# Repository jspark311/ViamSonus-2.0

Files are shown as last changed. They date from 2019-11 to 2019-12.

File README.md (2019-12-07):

# Viam Sonus 2.0

An audio router board with integrated volume control and buffered output.

### FEATURES:
  * 12 input channels that are arbitrarily routable to any of 8 output channels.
* Onboard digital potentiometers on the input side with non-volatile storage. Pots are logarithmic with zero-cross detection, and are paired in order with their input numbers on the board's silkscreen.
* Onboard op-amps on the output side with 300mA drive capability to provide buffering for direct-drive of line-level signals.
* Onboard buffered voltage divider with exposed output and 300mA drive capability to aid design and implementation of input buffers.
* Resistors added to the input-side of the switch, but after the potentiometers to allow for simple resistance mixing of signals simply by routing two inputs to a given output without risking damage. Some caveats apply (discussed below).
* Input-side is left free-form to allow use with single-ended (unbalanced) or differential (balanced) signals, and/or DC-biased sources.
* Safe for 5v audio signals.
* Isolated analog and digital power planes.
* Silkscreen reflects the envisioned usage (stereo signals), but the driver allows for easy grouping of any number of channels.
* Breadboard-friendly

#### [Hackaday.io Page](https://hackaday.io/project/168501-viam-sonus-20)

#### [Order from Tindie](https://www.tindie.com/products/18586/)

------------------------

### What is in this repository:

**./doc**:  Location for documentation

**./KiCAD**:  Hardware design files

**./Arduino**:  Arduino driver

**./linux**:  Linux wrappers and utility program

------------------------

### Encountering real world audio signals

#### Mixing, ducking, and cross-fade

To avoid damaging the board, input-side circuits should be designed to limit
peak channel currents if mixing is going to be used. Discourse on that topic can
be found in [a separate document](https://joshianlindsay.com/index.php?id=184).

#### Tips on channel layout

The driver sees the board as 12 mono inputs with discrete volume control routed
to 8 mono outputs. The driver presents a channel-grouping layer to the user application
that largely abstracts the underlying mono channels. But since the DS1881 was
intended as a stereo device, it has properties that support that use...

  * Resistances are matched on its two halves.
  * Both halves can be set with a single bus operation (and thus happen concurrently)

So if you intend on using Viam Sonus to handle stereo inputs, you _can_ use whatever
two channels for left and right that you like, and the driver will make it work. But it
will cost an extra bus operation to set the volume for the pair, and the channel
resistance match might be as loose as +/-20%. So if you can, you will get better
results by keeping stereo pairs on matched channels.

The output channels are also paired into the output buffers, but the choice of
keeping those matched (or not) will have less-tangible consequences.

------------------------

### Notes on driver features:

#### Channel grouping

By default, there are no channel groups, and the API operates on the level of
discrete mono channels. But many application will want to manage _groups of channels_.

Channel groups come in two flavors: Input and Output. Each type has a unique API.

#### Preserve-on-destroy

When the driver instance for the switch is destroyed, the default behavior is to
put the hardware into a known state (reset). This opens all routes. Use-cases
that want the hardware state to outlive the driver's life cycle are possible by
setting preserveOnDestroy(true) ahead of `init()`, like so...

    // Class initializes with the existing state of the hardware.
    vs.preserveOnDestroy(true);
    vs.init(&Wire);

Since `init()` will also call `reset()` by default, preserveOnDestroy must be
enabled prior to `init()` to achieve the desired result (both sides of the driver life cycle).

#### Preserving and restoring hardware states

The driver provides a means of cloning prior states to and from a buffer.
Possible reasons for doing this might be...

  * Higher bus efficiency during `init()`.
  * Major code savings, since you can skip configuring the hardware and the class with discrete function calls.
  * Storage of complete board configurations that can be fully re-established with a minimum of overhead.

Saving the current state can be done like this (from the example sketch)...

    uint8_t buffer[VIAMSONUS_SERIALIZE_SIZE];
    unsigned int written = vs.serialize(buffer, VIAMSONUS_SERIALIZE_SIZE);
    if (VIAMSONUS_SERIALIZE_SIZE == written) {
      // Everything worked. Do what you will with the buffer.
    }

Restoring the state from a buffer can be done either upon construction...

    uint8_t buf[VIAMSONUS_SERIALIZE_SIZE] = {
      0x01, 0x00, 0x00, 0x00, 0x00, 0x01, 0x70, 0x0A, 0x00, 0x00, 0x00, 0x00,
      0x00, 0x00, 0x00, 0x00, 0x00, 0x00, 0x00, 0x00, 0x00, 0x00, 0x01, 0x28,
      0x00, 0x3F, 0x3F, 0x06, 0x01, 0x28, 0x00, 0x3F, 0x3F, 0x06, 0x01, 0x29,
      0x00, 0x3F, 0x3F, 0x06, 0x01, 0x29, 0x00, 0x3F, 0x3F, 0x06, 0x01, 0x2A,
      0x00, 0x3F, 0x3F, 0x06, 0x01, 0x2A, 0x00, 0x3F, 0x3F, 0x06 ...
    };
    ViamSonus vs(buf, VIAMSONUS_SERIALIZE_SIZE);

...or after a successful `init()`...

    // Literally anywhere in the sketch...
    vs.unserialize(buf, VIAMSONUS_SERIALIZE_SIZE);

If done by construction, the configuration will be written to the class immediately,
and to the hardware during `init()`.

Invocation of `unserialize()` will immediately result in I/O as the new
configuration is imparted, but the fields (if any) that are otherwise required for
construction will be ignored.

------------------------

### Usage under Arduino

In order to use this driver, you also need the Arduino drivers for the elements on the board. Clone the following repos into your user libraries (wherever you keep them):

[DS1881 Driver](https://github.com/jspark311/DS1881-Breakout/tree/master/Arduino)

[ADG2128 Driver](https://github.com/jspark311/ADG2128-Breakout/tree/master/Arduino)

[StringBuilder and DataStructures](https://github.com/jspark311/CppPotpourri)

After you've done that, you ought to be able to include the ViamSonus driver.

------------------------

### Usage under Linux

Fortunately, the Viam Sonus router board doesn't have any interrupt pins, which makes running it in userland fairly easy with existing kernel drivers for i2c and GPIO. The reset pin isn't _strictly_ required. It can be tied high.

Just like the Arduino driver, you will need additional libraries. If you've already done
the setup for exposing the GPIO pin and i2c character device in your kernel config, you
ought to be able to do these things...

    git clone https://github.com/jspark311/ViamSonus-2.0.git
    cd ViamSonus-2.0/linux
    ./downloadDeps.sh
    make DEFAULT_I2C_DEV=/dev/i2c-1 DEFAULT_RESET_PIN=/sys/class/gpio/gpio18
    sudo make install

------------------------

Front | Back
:-------:|:------:
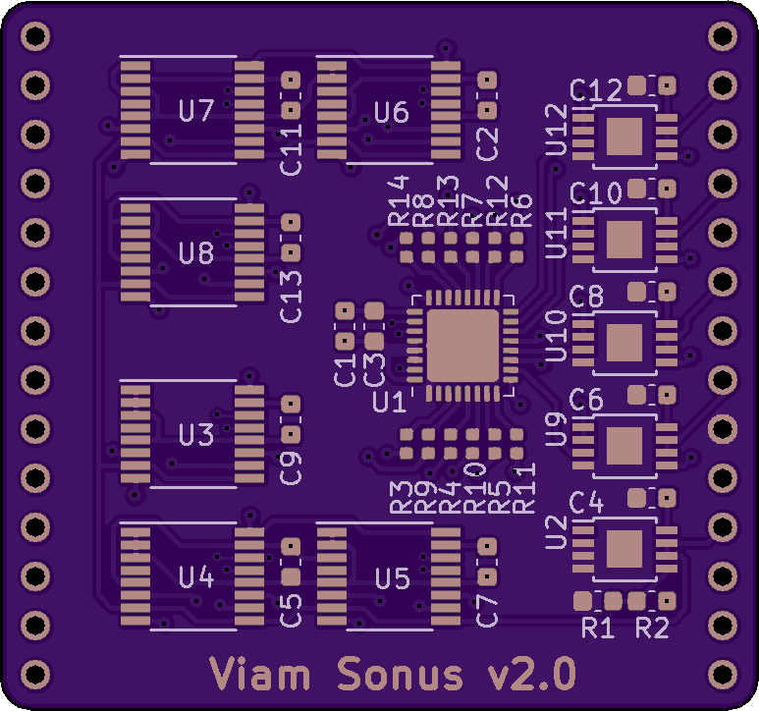
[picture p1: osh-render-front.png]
Front
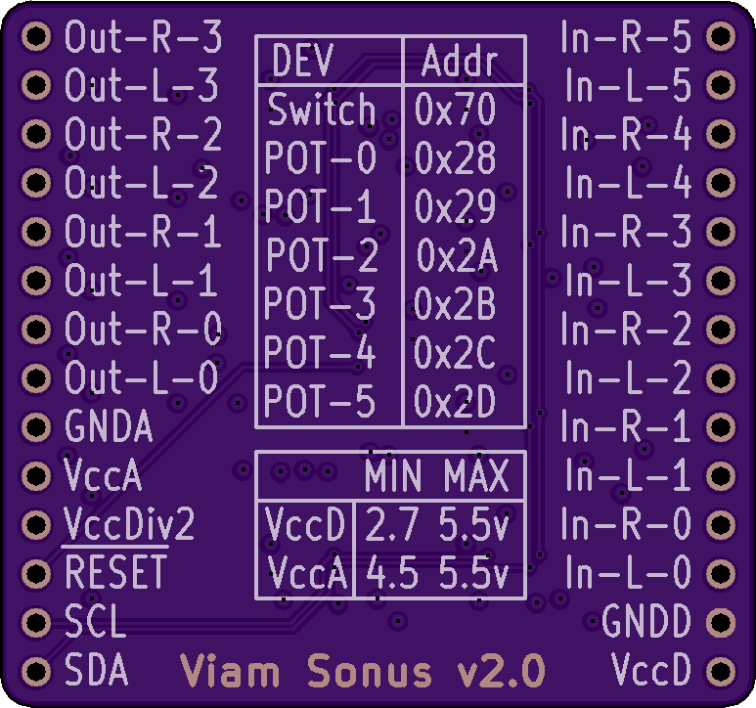
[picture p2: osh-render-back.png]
Back
  | 

[](https://oshpark.com/shared_projects/njoN7jnq)

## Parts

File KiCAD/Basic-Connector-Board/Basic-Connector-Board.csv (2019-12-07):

Reference | Value | Footprint | Datasheet | Digikey_Number | Manu_Name | Manu_Number
J11 | Conn_01x14_Male | Connector_PinHeader_2.54mm:PinHeader_1x14_P2.54mm_Vertical | ~
J12 | Conn_01x14_Male | Connector_PinHeader_2.54mm:PinHeader_1x14_P2.54mm_Vertical | ~
R6 | 20k | Resistor_SMD:R_0603_1608Metric | ~ | RNCP0603FTD20K0CT-ND | Stackpole Electronics Inc | RNCP0603FTD20K0
R5 | 20k | Resistor_SMD:R_0603_1608Metric | ~ | RNCP0603FTD20K0CT-ND | Stackpole Electronics Inc | RNCP0603FTD20K0
R12 | 20k | Resistor_SMD:R_0603_1608Metric | ~ | RNCP0603FTD20K0CT-ND | Stackpole Electronics Inc | RNCP0603FTD20K0
R11 | 20k | Resistor_SMD:R_0603_1608Metric | ~ | RNCP0603FTD20K0CT-ND | Stackpole Electronics Inc | RNCP0603FTD20K0
R4 | 20k | Resistor_SMD:R_0603_1608Metric | ~ | RNCP0603FTD20K0CT-ND | Stackpole Electronics Inc | RNCP0603FTD20K0
R3 | 20k | Resistor_SMD:R_0603_1608Metric | ~ | RNCP0603FTD20K0CT-ND | Stackpole Electronics Inc | RNCP0603FTD20K0
R10 | 20k | Resistor_SMD:R_0603_1608Metric | ~ | RNCP0603FTD20K0CT-ND | Stackpole Electronics Inc | RNCP0603FTD20K0
R9 | 20k | Resistor_SMD:R_0603_1608Metric | ~ | RNCP0603FTD20K0CT-ND | Stackpole Electronics Inc | RNCP0603FTD20K0
R2 | 20k | Resistor_SMD:R_0603_1608Metric | ~ | RNCP0603FTD20K0CT-ND | Stackpole Electronics Inc | RNCP0603FTD20K0
R1 | 20k | Resistor_SMD:R_0603_1608Metric | ~ | RNCP0603FTD20K0CT-ND | Stackpole Electronics Inc | RNCP0603FTD20K0
R8 | 20k | Resistor_SMD:R_0603_1608Metric | ~ | RNCP0603FTD20K0CT-ND | Stackpole Electronics Inc | RNCP0603FTD20K0
R7 | 20k | Resistor_SMD:R_0603_1608Metric | ~ | RNCP0603FTD20K0CT-ND | Stackpole Electronics Inc | RNCP0603FTD20K0
C20 | 3.3uF | Capacitor_SMD:CP_Elec_4x5.4 | ~ | 493-17493-1-ND | Nichicon | UUQ1H3R3MCL1GB
R18 | 20k | Resistor_SMD:R_0603_1608Metric | ~ | RNCP0603FTD20K0CT-ND | Stackpole Electronics Inc | RNCP0603FTD20K0
R17 | 20k | Resistor_SMD:R_0603_1608Metric | ~ | RNCP0603FTD20K0CT-ND | Stackpole Electronics Inc | RNCP0603FTD20K0
R24 | 20k | Resistor_SMD:R_0603_1608Metric | ~ | RNCP0603FTD20K0CT-ND | Stackpole Electronics Inc | RNCP0603FTD20K0
R23 | 20k | Resistor_SMD:R_0603_1608Metric | ~ | RNCP0603FTD20K0CT-ND | Stackpole Electronics Inc | RNCP0603FTD20K0
R16 | 20k | Resistor_SMD:R_0603_1608Metric | ~ | RNCP0603FTD20K0CT-ND | Stackpole Electronics Inc | RNCP0603FTD20K0
R15 | 20k | Resistor_SMD:R_0603_1608Metric | ~ | RNCP0603FTD20K0CT-ND | Stackpole Electronics Inc | RNCP0603FTD20K0
R22 | 20k | Resistor_SMD:R_0603_1608Metric | ~ | RNCP0603FTD20K0CT-ND | Stackpole Electronics Inc | RNCP0603FTD20K0
R21 | 20k | Resistor_SMD:R_0603_1608Metric | ~ | RNCP0603FTD20K0CT-ND | Stackpole Electronics Inc | RNCP0603FTD20K0
R14 | 20k | Resistor_SMD:R_0603_1608Metric | ~ | RNCP0603FTD20K0CT-ND | Stackpole Electronics Inc | RNCP0603FTD20K0
R13 | 20k | Resistor_SMD:R_0603_1608Metric | ~ | RNCP0603FTD20K0CT-ND | Stackpole Electronics Inc | RNCP0603FTD20K0
R20 | 20k | Resistor_SMD:R_0603_1608Metric | ~ | RNCP0603FTD20K0CT-ND | Stackpole Electronics Inc | RNCP0603FTD20K0
R19 | 20k | Resistor_SMD:R_0603_1608Metric | ~ | RNCP0603FTD20K0CT-ND | Stackpole Electronics Inc | RNCP0603FTD20K0
C3 | 100uF | Capacitor_SMD:CP_Elec_6.3x5.4_Nichicon | ~ | 493-16090-1-ND | Nichicon | UUQ0J101MCL1GB
J13 | Conn_01x04 | Connector_PinHeader_2.54mm:PinHeader_1x04_P2.54mm_Horizontal | ~
J14 | Conn_01x04 | Connector_PinHeader_2.54mm:PinHeader_1x04_P2.54mm_Horizontal | ~
C4 | 100uF | Capacitor_SMD:CP_Elec_6.3x5.4_Nichicon | ~ | 493-16090-1-ND | Nichicon | UUQ0J101MCL1GB
C2 | 100uF | Capacitor_SMD:CP_Elec_6.3x5.4_Nichicon | ~ | 493-16090-1-ND | Nichicon | UUQ0J101MCL1GB
C1 | 100uF | Capacitor_SMD:CP_Elec_6.3x5.4_Nichicon | ~ | 493-16090-1-ND | Nichicon | UUQ0J101MCL1GB
C11 | 100uF | Capacitor_SMD:CP_Elec_6.3x5.4_Nichicon | ~ | 493-16090-1-ND | Nichicon | UUQ0J101MCL1GB
C12 | 100uF | Capacitor_SMD:CP_Elec_6.3x5.4_Nichicon | ~ | 493-16090-1-ND | Nichicon | UUQ0J101MCL1GB
C13 | 100uF | Capacitor_SMD:CP_Elec_6.3x5.4_Nichicon | ~ | 493-16090-1-ND | Nichicon | UUQ0J101MCL1GB
C14 | 100uF | Capacitor_SMD:CP_Elec_6.3x5.4_Nichicon | ~ | 493-16090-1-ND | Nichicon | UUQ0J101MCL1GB
C19 | 3.3uF | Capacitor_SMD:CP_Elec_4x5.4 | ~ | 493-17493-1-ND | Nichicon | UUQ1H3R3MCL1GB
C18 | 3.3uF | Capacitor_SMD:CP_Elec_4x5.4 | ~ | 493-17493-1-ND | Nichicon | UUQ1H3R3MCL1GB
C17 | 3.3uF | Capacitor_SMD:CP_Elec_4x5.4 | ~ | 493-17493-1-ND | Nichicon | UUQ1H3R3MCL1GB
C16 | 3.3uF | Capacitor_SMD:CP_Elec_4x5.4 | ~ | 493-17493-1-ND | Nichicon | UUQ1H3R3MCL1GB
C15 | 3.3uF | Capacitor_SMD:CP_Elec_4x5.4 | ~ | 493-17493-1-ND | Nichicon | UUQ1H3R3MCL1GB
C10 | 3.3uF | Capacitor_SMD:CP_Elec_4x5.4 | ~ | 493-17493-1-ND | Nichicon | UUQ1H3R3MCL1GB
C9 | 3.3uF | Capacitor_SMD:CP_Elec_4x5.4 | ~ | 493-17493-1-ND | Nichicon | UUQ1H3R3MCL1GB
C8 | 3.3uF | Capacitor_SMD:CP_Elec_4x5.4 | ~ | 493-17493-1-ND | Nichicon | UUQ1H3R3MCL1GB
C7 | 3.3uF | Capacitor_SMD:CP_Elec_4x5.4 | ~ | 493-17493-1-ND | Nichicon | UUQ1H3R3MCL1GB
C6 | 3.3uF | Capacitor_SMD:CP_Elec_4x5.4 | ~ | 493-17493-1-ND | Nichicon | UUQ1H3R3MCL1GB
C5 | 3.3uF | Capacitor_SMD:CP_Elec_4x5.4 | ~ | 493-17493-1-ND | Nichicon | UUQ1H3R3MCL1GB
U1 | LM1085 | Package_TO_SOT_SMD:TO-263-3_TabPin2 |  | 296-35391-1-ND | Texas Instruments | LM1085ISX-5.0/NOPB
C21 | 10uF | Capacitor_SMD:CP_Elec_4x5.4 | ~ | 493-14558-1-ND | Nichicon | UUQ11C100MCL1GB
C22 | 10uF | Capacitor_SMD:CP_Elec_4x5.4 | ~ | 493-14558-1-ND | Nichicon | UUQ11C100MCL1GB
R38 | 2k | Resistor_SMD:R_0603_1608Metric | ~ | RNCP0603FTD2K00CT-ND | Stackpole Electronics Inc | RNCP0603FTD2K00
R37 | 2k | Resistor_SMD:R_0603_1608Metric | ~ | RNCP0603FTD2K00CT-ND | Stackpole Electronics Inc | RNCP0603FTD2K00
R36 | 2k | Resistor_SMD:R_0603_1608Metric | ~ | RNCP0603FTD2K00CT-ND | Stackpole Electronics Inc | RNCP0603FTD2K00
R35 | 2k | Resistor_SMD:R_0603_1608Metric | ~ | RNCP0603FTD2K00CT-ND | Stackpole Electronics Inc | RNCP0603FTD2K00
R34 | 2k | Resistor_SMD:R_0603_1608Metric | ~ | RNCP0603FTD2K00CT-ND | Stackpole Electronics Inc | RNCP0603FTD2K00
R33 | 2k | Resistor_SMD:R_0603_1608Metric | ~ | RNCP0603FTD2K00CT-ND | Stackpole Electronics Inc | RNCP0603FTD2K00
R28 | 2k | Resistor_SMD:R_0603_1608Metric | ~ | RNCP0603FTD2K00CT-ND | Stackpole Electronics Inc | RNCP0603FTD2K00
R27 | 2k | Resistor_SMD:R_0603_1608Metric | ~ | RNCP0603FTD2K00CT-ND | Stackpole Electronics Inc | RNCP0603FTD2K00
R30 | 2k | Resistor_SMD:R_0603_1608Metric | ~ | RNCP0603FTD2K00CT-ND | Stackpole Electronics Inc | RNCP0603FTD2K00
R29 | 2k | Resistor_SMD:R_0603_1608Metric | ~ | RNCP0603FTD2K00CT-ND | Stackpole Electronics Inc | RNCP0603FTD2K00
R32 | 2k | Resistor_SMD:R_0603_1608Metric | ~ | RNCP0603FTD2K00CT-ND | Stackpole Electronics Inc | RNCP0603FTD2K00
R31 | 2k | Resistor_SMD:R_0603_1608Metric | ~ | RNCP0603FTD2K00CT-ND | Stackpole Electronics Inc | RNCP0603FTD2K00
R25 | 2k | Resistor_SMD:R_0603_1608Metric | ~ | RNCP0603FTD2K00CT-ND | Stackpole Electronics Inc | RNCP0603FTD2K00
R26 | 2k | Resistor_SMD:R_0603_1608Metric | ~ | RNCP0603FTD2K00CT-ND | Stackpole Electronics Inc | RNCP0603FTD2K00
C23 | 100uF | Capacitor_SMD:CP_Elec_6.3x5.4_Nichicon | ~ | 493-16090-1-ND | Nichicon | UUQ0J101MCL1GB
C24 | 100uF | Capacitor_SMD:CP_Elec_6.3x5.4_Nichicon | ~ | 493-16090-1-ND | Nichicon | UUQ0J101MCL1GB
J4 | AudioJack3_Ground_Switch | Footprints:SJ2-3593D-SMT-TR | ~ | CP-SJ2-3593D-SMT-CT-ND | CUI Devices | SJ2-3593D-SMT-TR
J5 | AudioJack3_Ground_Switch | Footprints:SJ2-3593D-SMT-TR | ~ | CP-SJ2-3593D-SMT-CT-ND | CUI Devices | SJ2-3593D-SMT-TR
J6 | AudioJack3_Ground_Switch | Footprints:SJ2-3593D-SMT-TR | ~ | CP-SJ2-3593D-SMT-CT-ND | CUI Devices | SJ2-3593D-SMT-TR
J3 | AudioJack3_Ground_Switch | Footprints:SJ2-3593D-SMT-TR | ~ | CP-SJ2-3593D-SMT-CT-ND | CUI Devices | SJ2-3593D-SMT-TR
J2 | AudioJack3_Ground_Switch | Footprints:SJ2-3593D-SMT-TR | ~ | CP-SJ2-3593D-SMT-CT-ND | CUI Devices | SJ2-3593D-SMT-TR
J1 | AudioJack3_Ground_Switch | Footprints:SJ2-3593D-SMT-TR | ~ | CP-SJ2-3593D-SMT-CT-ND | CUI Devices | SJ2-3593D-SMT-TR
J7 | AudioJack3_Ground_Switch | Footprints:SJ2-3593D-SMT-TR | ~ | CP-SJ2-3593D-SMT-CT-ND | CUI Devices | SJ2-3593D-SMT-TR
J8 | AudioJack3_Ground_Switch | Footprints:SJ2-3593D-SMT-TR | ~ | CP-SJ2-3593D-SMT-CT-ND | CUI Devices | SJ2-3593D-SMT-TR
J10 | AudioJack3_Ground_Switch | Footprints:SJ2-3593D-SMT-TR | ~ | CP-SJ2-3593D-SMT-CT-ND | CUI Devices | SJ2-3593D-SMT-TR
J9 | AudioJack3_Ground_Switch | Footprints:SJ2-3593D-SMT-TR | ~ | CP-SJ2-3593D-SMT-CT-ND | CUI Devices | SJ2-3593D-SMT-TR
R42 | 20k | Resistor_SMD:R_0603_1608Metric | ~ | RNCP0603FTD20K0CT-ND | Stackpole Electronics Inc | RNCP0603FTD20K0
R44 | 20k | Resistor_SMD:R_0603_1608Metric | ~ | RNCP0603FTD20K0CT-ND | Stackpole Electronics Inc | RNCP0603FTD20K0
R39 | 20k | Resistor_SMD:R_0603_1608Metric | ~ | RNCP0603FTD20K0CT-ND | Stackpole Electronics Inc | RNCP0603FTD20K0
R43 | 20k | Resistor_SMD:R_0603_1608Metric | ~ | RNCP0603FTD20K0CT-ND | Stackpole Electronics Inc | RNCP0603FTD20K0
R40 | 20k | Resistor_SMD:R_0603_1608Metric | ~ | RNCP0603FTD20K0CT-ND | Stackpole Electronics Inc | RNCP0603FTD20K0
R41 | 20k | Resistor_SMD:R_0603_1608Metric | ~ | RNCP0603FTD20K0CT-ND | Stackpole Electronics Inc | RNCP0603FTD20K0
J15 | 6.5 - 20v | Footprints:PJ-063AH | ~ | CP-063AH-ND | CUI Devices | PJ-063AH

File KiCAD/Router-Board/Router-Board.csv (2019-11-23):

Reference | Value | Footprint | Datasheet | Digikey_Num | Manu_Name | Manu_Num
U1 | ADG2128 | Package_DFN_QFN:QFN-32-1EP_5x5mm_P0.5mm_EP3.65x3.65mm |  | ADG2128YCPZ-REEL7CT-ND | Analog Devices Inc. | ADG2128YCPZ-REEL7
U3 | DS1881E-050+ | Package_SO:TSSOP-16_4.4x5mm_P0.65mm |  | DS1881E-050+-ND | Maxim Integrated | DS1881E-050+
U11 | LME49726MY/NOPB | Footprints:TSSOP-8_3x3mm_P0.65mm-EP |  | LME49726MY/NOPBCT-ND | Texas Instruments | LME49726MY/NOPB
C10 | 1uF | Capacitor_SMD:C_0603_1608Metric | ~ | 445-13228-1-ND | TDK Corporation | CGB3B1X7R1A105K055AC
U4 | DS1881E-050+ | Package_SO:TSSOP-16_4.4x5mm_P0.65mm |  | DS1881E-050+-ND | Maxim Integrated | DS1881E-050+
U5 | DS1881E-050+ | Package_SO:TSSOP-16_4.4x5mm_P0.65mm |  | DS1881E-050+-ND | Maxim Integrated | DS1881E-050+
U6 | DS1881E-050+ | Package_SO:TSSOP-16_4.4x5mm_P0.65mm |  | DS1881E-050+-ND | Maxim Integrated | DS1881E-050+
U7 | DS1881E-050+ | Package_SO:TSSOP-16_4.4x5mm_P0.65mm |  | DS1881E-050+-ND | Maxim Integrated | DS1881E-050+
U8 | DS1881E-050+ | Package_SO:TSSOP-16_4.4x5mm_P0.65mm |  | DS1881E-050+-ND | Maxim Integrated | DS1881E-050+
U10 | LME49726MY/NOPB | Footprints:TSSOP-8_3x3mm_P0.65mm-EP |  | LME49726MY/NOPBCT-ND | Texas Instruments | LME49726MY/NOPB
U9 | LME49726MY/NOPB | Footprints:TSSOP-8_3x3mm_P0.65mm-EP |  | LME49726MY/NOPBCT-ND | Texas Instruments | LME49726MY/NOPB
U12 | LME49726MY/NOPB | Footprints:TSSOP-8_3x3mm_P0.65mm-EP |  | LME49726MY/NOPBCT-ND | Texas Instruments | LME49726MY/NOPB
U2 | LME49726MY/NOPB | Footprints:TSSOP-8_3x3mm_P0.65mm-EP |  | LME49726MY/NOPBCT-ND | Texas Instruments | LME49726MY/NOPB
R1 | 51k | Resistor_SMD:R_0603_1608Metric | ~ | RMCF0603FT51K0CT-ND | Stackpole Electronics Inc | Stackpole Electronics Inc
R3 | 330 | Resistor_SMD:R_0402_1005Metric | ~ | 2019-RK73H1ETTP3300FCT-ND | KOA Speer Electronics, Inc. | RK73H1ETTP3300F
J2 | Conn_01x14_Male | Connector_PinHeader_2.54mm:PinHeader_1x14_P2.54mm_Vertical | ~
J3 | Conn_01x14_Male | Connector_PinHeader_2.54mm:PinHeader_1x14_P2.54mm_Vertical | ~
C8 | 1uF | Capacitor_SMD:C_0603_1608Metric | ~ | 445-13228-1-ND | TDK Corporation | CGB3B1X7R1A105K055AC
C6 | 1uF | Capacitor_SMD:C_0603_1608Metric | ~ | 445-13228-1-ND | TDK Corporation | CGB3B1X7R1A105K055AC
C4 | 1uF | Capacitor_SMD:C_0603_1608Metric | ~ | 445-13228-1-ND | TDK Corporation | CGB3B1X7R1A105K055AC
C12 | 1uF | Capacitor_SMD:C_0603_1608Metric | ~ | 445-13228-1-ND | TDK Corporation | CGB3B1X7R1A105K055AC
C1 | 1uF | Capacitor_SMD:C_0603_1608Metric | ~ | 445-13228-1-ND | TDK Corporation | CGB3B1X7R1A105K055AC
C2 | 1uF | Capacitor_SMD:C_0603_1608Metric | ~ | 445-13228-1-ND | TDK Corporation | CGB3B1X7R1A105K055AC
C3 | 1uF | Capacitor_SMD:C_0603_1608Metric | ~ | 445-13228-1-ND | TDK Corporation | CGB3B1X7R1A105K055AC
C5 | 1uF | Capacitor_SMD:C_0603_1608Metric | ~ | 445-13228-1-ND | TDK Corporation | CGB3B1X7R1A105K055AC
C7 | 1uF | Capacitor_SMD:C_0603_1608Metric | ~ | 445-13228-1-ND | TDK Corporation | CGB3B1X7R1A105K055AC
C9 | 1uF | Capacitor_SMD:C_0603_1608Metric | ~ | 445-13228-1-ND | TDK Corporation | CGB3B1X7R1A105K055AC
C11 | 1uF | Capacitor_SMD:C_0603_1608Metric | ~ | 445-13228-1-ND | TDK Corporation | CGB3B1X7R1A105K055AC
C13 | 1uF | Capacitor_SMD:C_0603_1608Metric | ~ | 445-13228-1-ND | TDK Corporation | CGB3B1X7R1A105K055AC
R2 | 51k | Resistor_SMD:R_0603_1608Metric | ~ | RMCF0603FT51K0CT-ND | Stackpole Electronics Inc | Stackpole Electronics Inc
R9 | 330 | Resistor_SMD:R_0402_1005Metric | ~ | 2019-RK73H1ETTP3300FCT-ND | KOA Speer Electronics, Inc. | RK73H1ETTP3300F
R10 | 330 | Resistor_SMD:R_0402_1005Metric | ~ | 2019-RK73H1ETTP3300FCT-ND | KOA Speer Electronics, Inc. | RK73H1ETTP3300F
R11 | 330 | Resistor_SMD:R_0402_1005Metric | ~ | 2019-RK73H1ETTP3300FCT-ND | KOA Speer Electronics, Inc. | RK73H1ETTP3300F
R12 | 330 | Resistor_SMD:R_0402_1005Metric | ~ | 2019-RK73H1ETTP3300FCT-ND | KOA Speer Electronics, Inc. | RK73H1ETTP3300F
R13 | 330 | Resistor_SMD:R_0402_1005Metric | ~ | 2019-RK73H1ETTP3300FCT-ND | KOA Speer Electronics, Inc. | RK73H1ETTP3300F
R14 | 330 | Resistor_SMD:R_0402_1005Metric | ~ | 2019-RK73H1ETTP3300FCT-ND | KOA Speer Electronics, Inc. | RK73H1ETTP3300F
R8 | 330 | Resistor_SMD:R_0402_1005Metric | ~ | 2019-RK73H1ETTP3300FCT-ND | KOA Speer Electronics, Inc. | RK73H1ETTP3300F
R7 | 330 | Resistor_SMD:R_0402_1005Metric | ~ | 2019-RK73H1ETTP3300FCT-ND | KOA Speer Electronics, Inc. | RK73H1ETTP3300F
R6 | 330 | Resistor_SMD:R_0402_1005Metric | ~ | 2019-RK73H1ETTP3300FCT-ND | KOA Speer Electronics, Inc. | RK73H1ETTP3300F
R5 | 330 | Resistor_SMD:R_0402_1005Metric | ~ | 2019-RK73H1ETTP3300FCT-ND | KOA Speer Electronics, Inc. | RK73H1ETTP3300F
R4 | 330 | Resistor_SMD:R_0402_1005Metric | ~ | 2019-RK73H1ETTP3300FCT-ND | KOA Speer Electronics, Inc. | RK73H1ETTP3300F

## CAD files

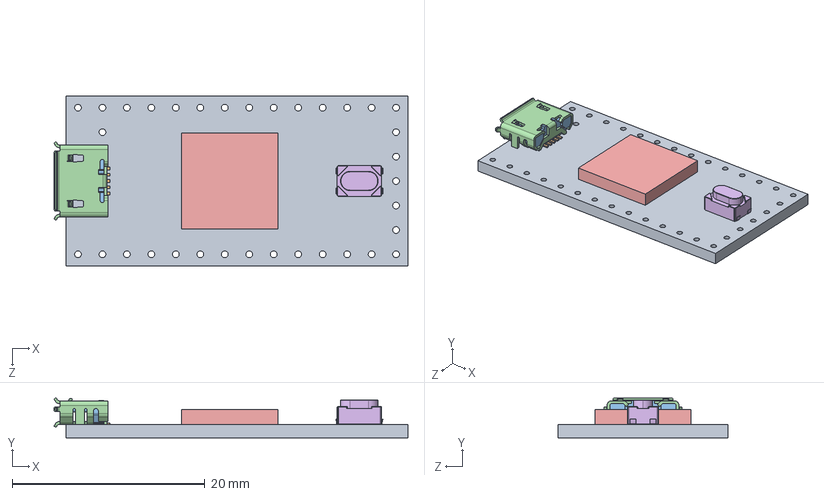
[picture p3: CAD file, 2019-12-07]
KiCAD/Footprints/Teensy_4.0_Assembly.STEP
36.8 x 4.12 x 17.7 mm
Teensy_4.0_PCB
Micro USB-B Female 5Pin SMD
NXP iMXRT1062
SKRPACE010 v4

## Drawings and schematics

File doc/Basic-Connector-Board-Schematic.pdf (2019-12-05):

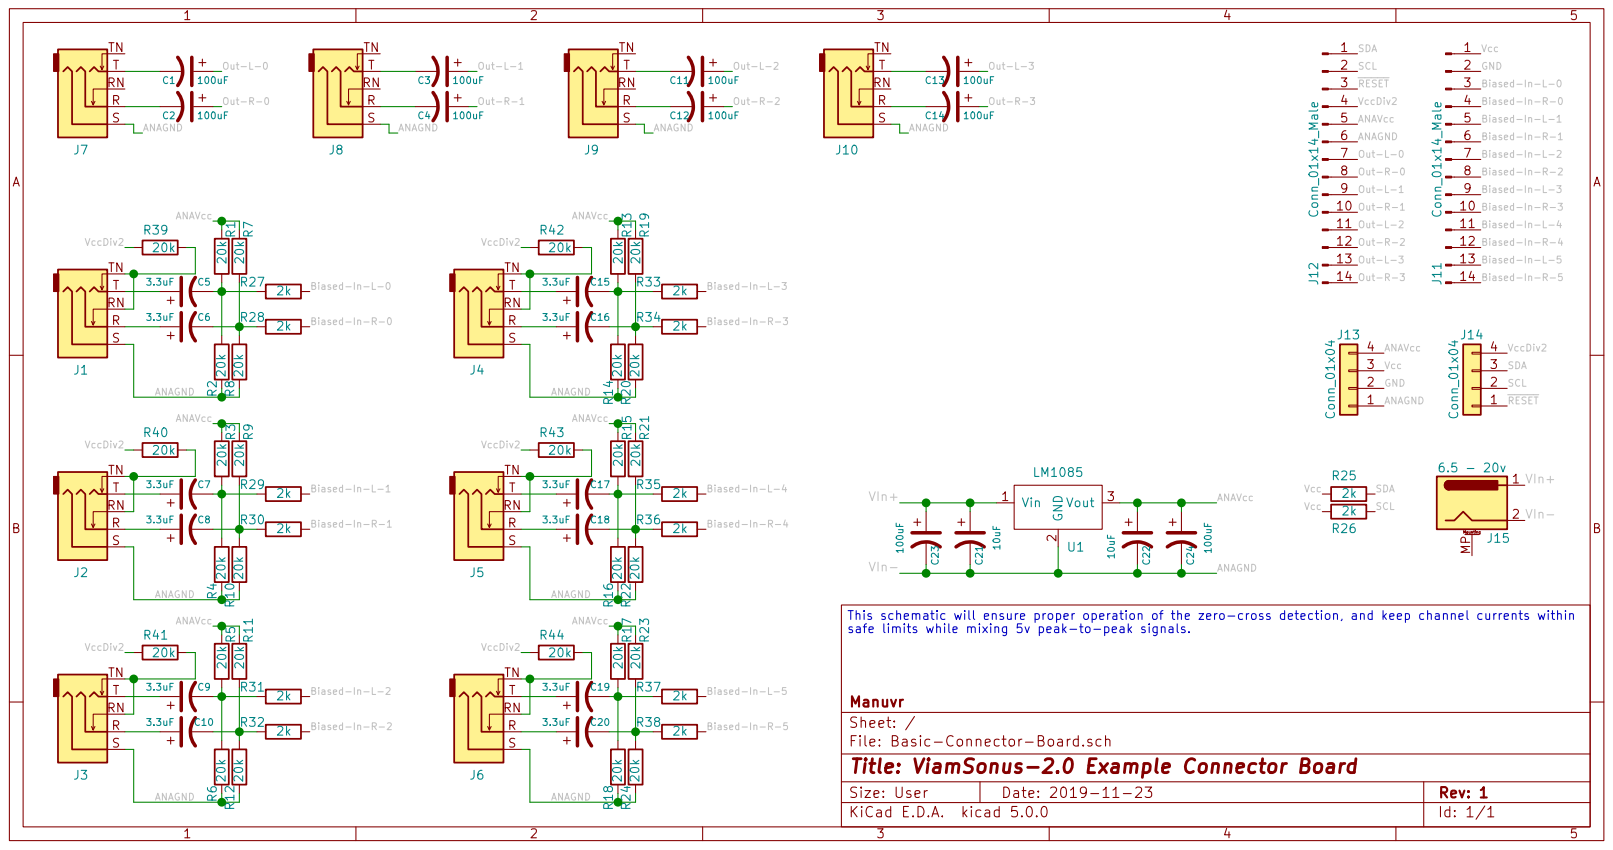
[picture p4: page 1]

Biased-In-L-0 Biased-In-L-1 Biased-In-L-2 Biased-In-L-3 Biased-In-L-4 Biased-In-L-5 Biased-In-R-0 Biased-In-R-1 Biased-In-R-2 Biased-In-R-3 Biased-In-R-4 Biased-In-R-5 Out-L-0 Out-L-1 Out-L-2 Out-L-3 Out-R-0 Out-R-1 Out-R-2 Out-R-3 R6 20k ANAGND

This schematic will ensure proper operation of the zero-cross detection, and keep channel currents within

File: Basic-Connector-Board.sch Sheet: / Manuvr

Id: 1/1 Title: ViamSonus-2.0 Example Connector Board

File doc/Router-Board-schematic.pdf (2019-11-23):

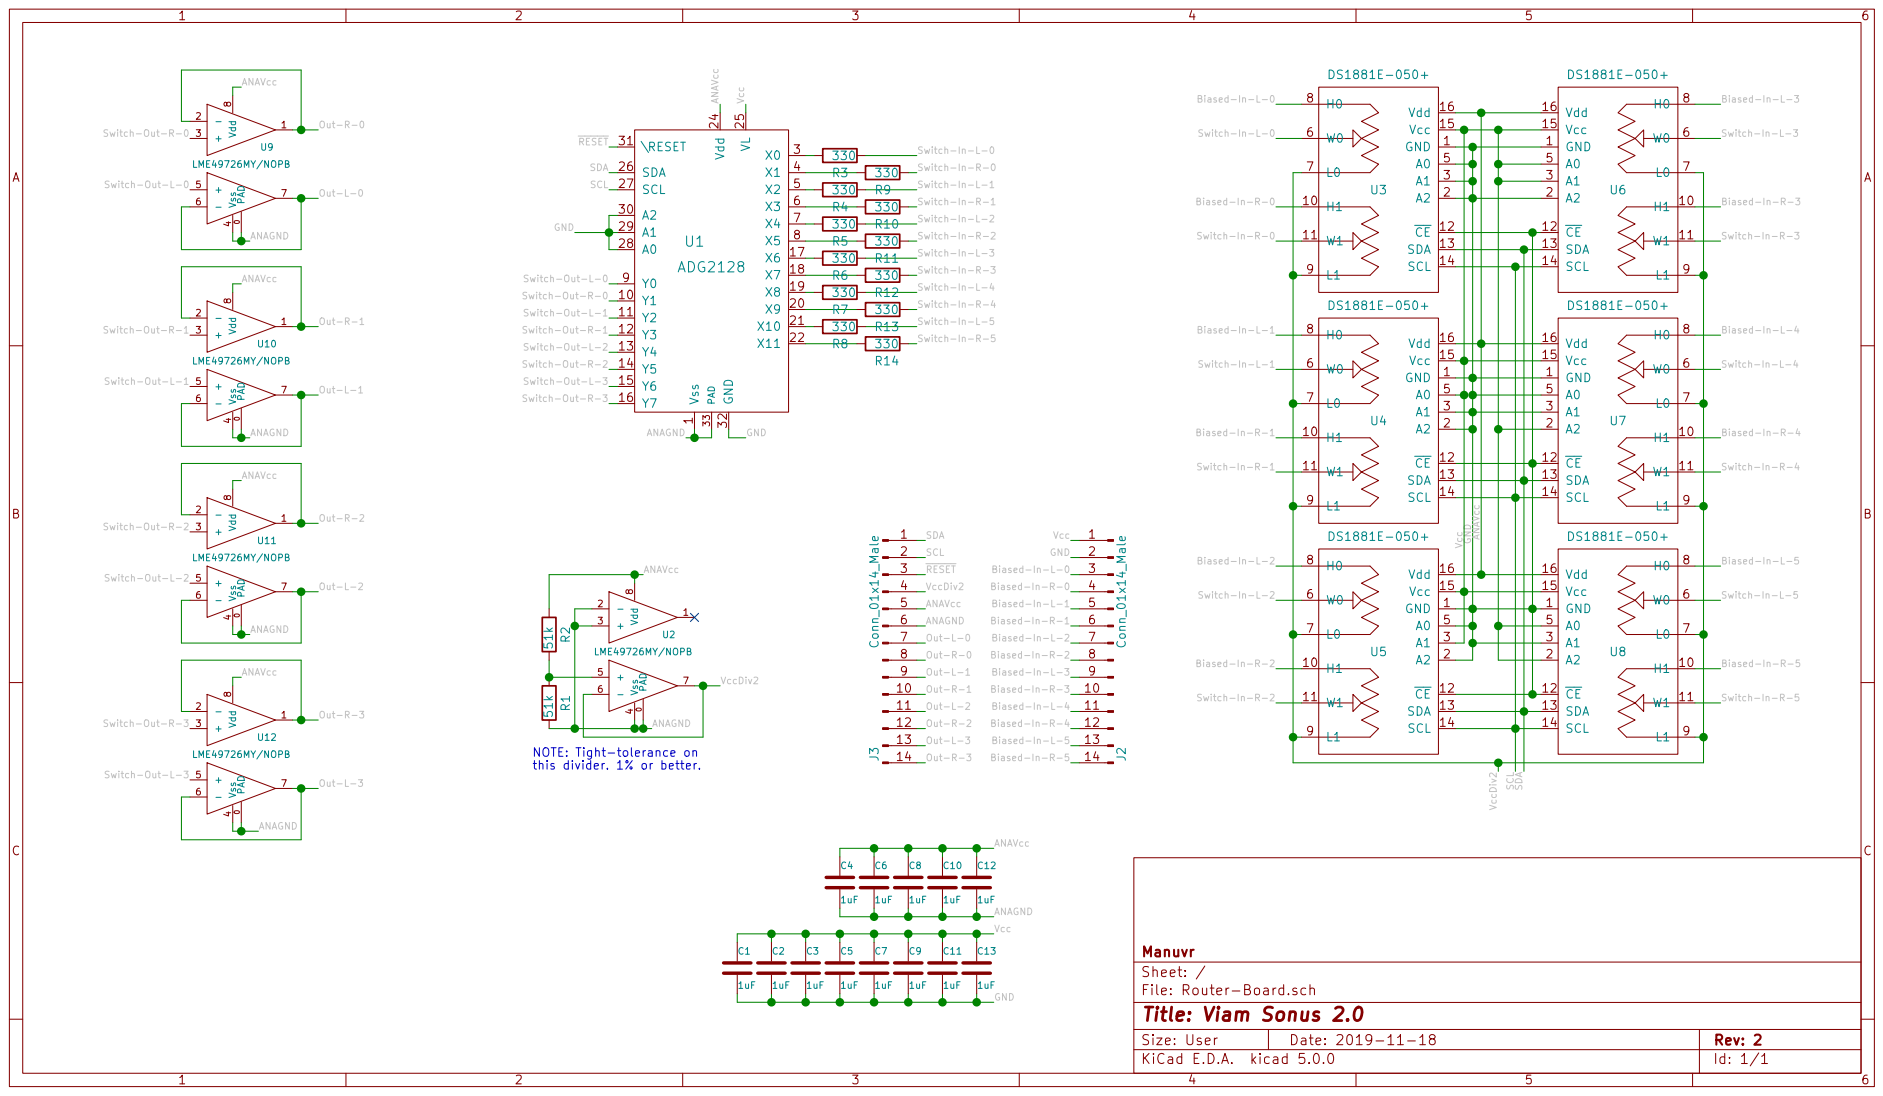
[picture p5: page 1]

Switch-Out-R-0 Switch-Out-R-1 Switch-Out-R-2 Switch-Out-R-3
Switch-Out-L-0 Switch-Out-L-1 Switch-Out-L-2 Switch-Out-L-3

Out-R-0 Out-R-1 Out-R-2 Out-R-3

Biased-In-L-0 Biased-In-L-1 Biased-In-L-2
Switch-In-L-0 Switch-In-L-1 Switch-In-L-2
Biased-In-R-0 Biased-In-R-1 Biased-In-R-2

Biased-In-R-3 Biased-In-R-4 Biased-In-R-5

Switch-In-L-3 Switch-In-L-4 Switch-In-L-5 Switch-In-R-0 Switch-In-R-1 Switch-In-R-2

Out-L-0 Out-L-1 Out-L-2 Out-L-3

Switch-In-R-3 Switch-In-R-4 Switch-In-R-5 SCL SDA

Id: 1/1 Title: Viam Sonus 2.0

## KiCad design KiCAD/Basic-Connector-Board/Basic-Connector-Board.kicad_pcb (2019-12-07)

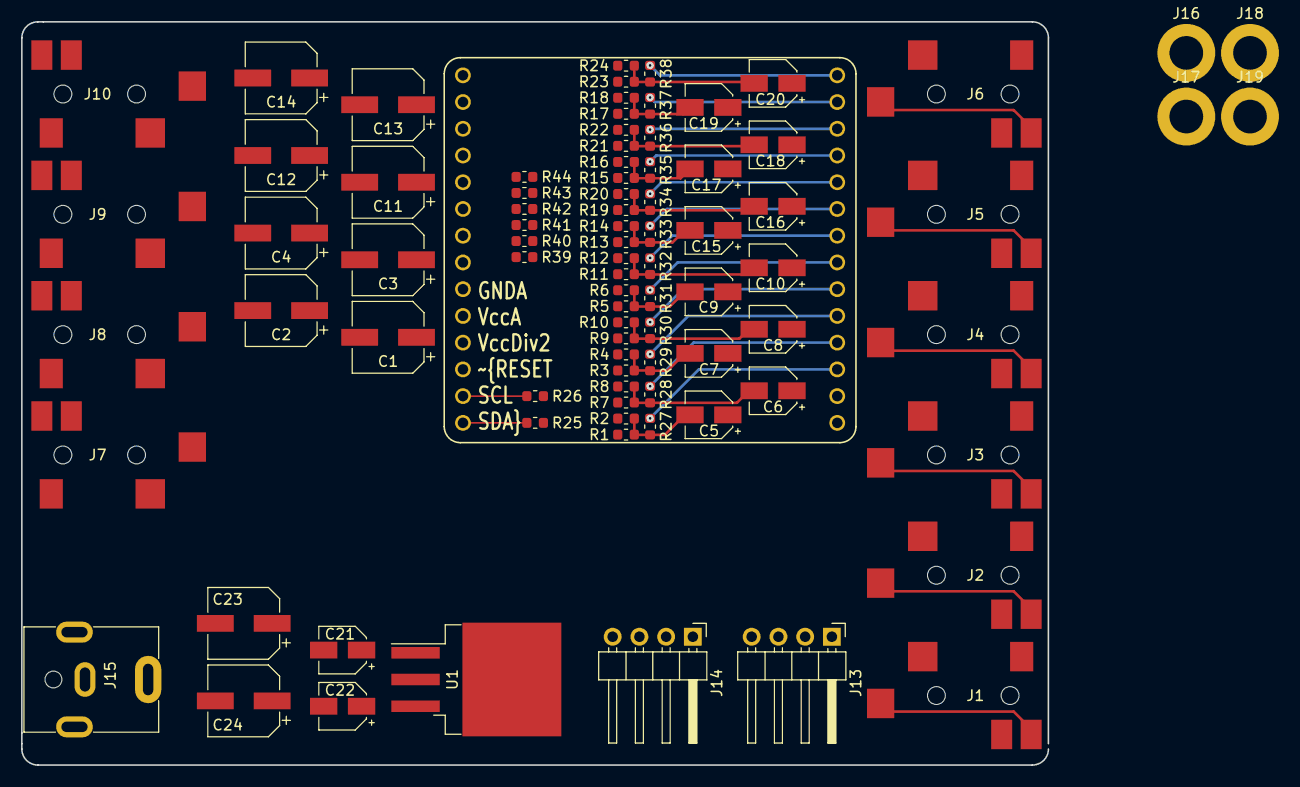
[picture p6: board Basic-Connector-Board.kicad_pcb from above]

Board: 4 copper layers, 97.5 x 70.6 mm, 88 parts (1 on the bottom side), 67 nets.

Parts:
C1, C2, C3, C4, C11, C12, C13, C14, C23, C24: 100uF; CP_Elec_6.3x5.4_Nichicon
C5, C6, C7, C8, C9, C10, C15, C16, C17, C18, C19, C20: 3.3uF; CP_Elec_4x5.4
C21, C22: 10uF; CP_Elec_4x5.4
J1, J2, J3, J4, J5, J6, J7, J8, J9, J10: AudioJack3_Ground_Switch; SJ2-3593D-SMT-TR
J11, J12: Conn_01x14_Male; PinHeader_1x14_P2.54mm_Vertical
J13, J14: Conn_01x04; PinHeader_1x04_P2.54mm_Horizontal
J15: 6.5 - 20v; PJ-063AH
J16, J17, J18, J19: Conn_01x01; MountingHole_3.2mm_M3_ISO14580_Pad
R1, R2, R3, R4, R5, R6, R7, R8, R9, R10, R11, R12, R13, R14, R15, R16, R17, R18, R19, R20, R21, R22, R23, R24, R39, R40, R41, R42, R43, R44: 20k; R_0603_1608Metric
R25, R26, R27, R28, R29, R30, R31, R32, R33, R34, R35, R36, R37, R38: 2k; R_0603_1608Metric
U1: LM1085; TO-263-3_TabPin2

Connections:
/ANAGND: C21.2, C22.2, C23.2, C24.2, J1.S, J2.S, J3.S, J4.S, J5.S, J6.S, J7.S, J8.S, J9.S, J10.S, J12.6, J13.1, J15.2, R2.1, R4.1, R6.1, R8.1, R10.1, R12.1, R14.1, R16.1, R18.1, R20.1, R22.1, R24.1, U1.2
/ANAVcc: C22.1, C24.1, J12.5, J13.4, R1.1, R3.1, R5.1, R7.1, R9.1, R11.1, R13.1, R15.1, R17.1, R19.1, R21.1, R23.1, U1.3
/Biased-In-L-0: J11.3, R27.2
/Biased-In-L-1: J11.5, R29.2
/Biased-In-L-2: J11.7, R31.2
/Biased-In-L-3: J11.9, R33.2
/Biased-In-L-4: J11.11, R35.2
/Biased-In-L-5: J11.13, R37.2
/Biased-In-R-0: J11.4, R28.2
/Biased-In-R-1: J11.6, R30.2
/Biased-In-R-2: J11.8, R32.2
/Biased-In-R-3: J11.10, R34.2
/Biased-In-R-4: J11.12, R36.2
/Biased-In-R-5: J11.14, R38.2
/GND: J11.2, J13.2, J16.1, J17.1, J18.1, J19.1
/Out-L-0: C1.1, J12.7
/Out-L-1: C3.1, J12.9
/Out-L-2: C11.1, J12.11
/Out-L-3: C13.1, J12.13
/Out-R-0: C2.1, J12.8
/Out-R-1: C4.1, J12.10
/Out-R-2: C12.1, J12.12
/Out-R-3: C14.1, J12.14
/SCL: J12.2, J14.2, R26.2
/SDA: J12.1, J14.3, R25.2
/VIn+: C21.1, C23.1, J15.1, U1.1
/Vcc: J11.1, J13.3, R25.1, R26.1
/VccDiv2: J12.4, J14.4, R39.2, R40.2, R41.2, R42.2, R43.2, R44.2
/~RESET: J12.3, J14.1
unnamed: C1.2, J7.T
unnamed: C2.2, J7.R
unnamed: C3.2, J8.T
unnamed: C4.2, J8.R
unnamed: C5.1, J1.T
unnamed: C5.2, R1.2, R2.2, R27.1
unnamed: C6.1, J1.R
unnamed: C6.2, R7.2, R8.2, R28.1
unnamed: C7.1, J2.T
unnamed: C7.2, R3.2, R4.2, R29.1
unnamed: C8.1, J2.R
unnamed: C8.2, R9.2, R10.2, R30.1
unnamed: C9.1, J3.T
unnamed: C9.2, R5.2, R6.2, R31.1
unnamed: C10.1, J3.R
unnamed: C10.2, R11.2, R12.2, R32.1
unnamed: C11.2, J9.T
unnamed: C12.2, J9.R
unnamed: C13.2, J10.T
unnamed: C14.2, J10.R
unnamed: C15.1, J4.T
unnamed: C15.2, R13.2, R14.2, R33.1
unnamed: C16.1, J4.R
unnamed: C16.2, R19.2, R20.2, R34.1
unnamed: C17.1, J5.T
unnamed: C17.2, R15.2, R16.2, R35.1
unnamed: C18.1, J5.R
unnamed: C18.2, R21.2, R22.2, R36.1
unnamed: C19.1, J6.T
unnamed: C19.2, R17.2, R18.2, R37.1
unnamed: C20.1, J6.R
unnamed: C20.2, R23.2, R24.2, R38.1
unnamed: J1.RN, J1.TN, R39.1
unnamed: J2.RN, J2.TN, R40.1
unnamed: J3.RN, J3.TN, R41.1
unnamed: J4.RN, J4.TN, R42.1
unnamed: J5.RN, J5.TN, R43.1
unnamed: J6.RN, J6.TN, R44.1

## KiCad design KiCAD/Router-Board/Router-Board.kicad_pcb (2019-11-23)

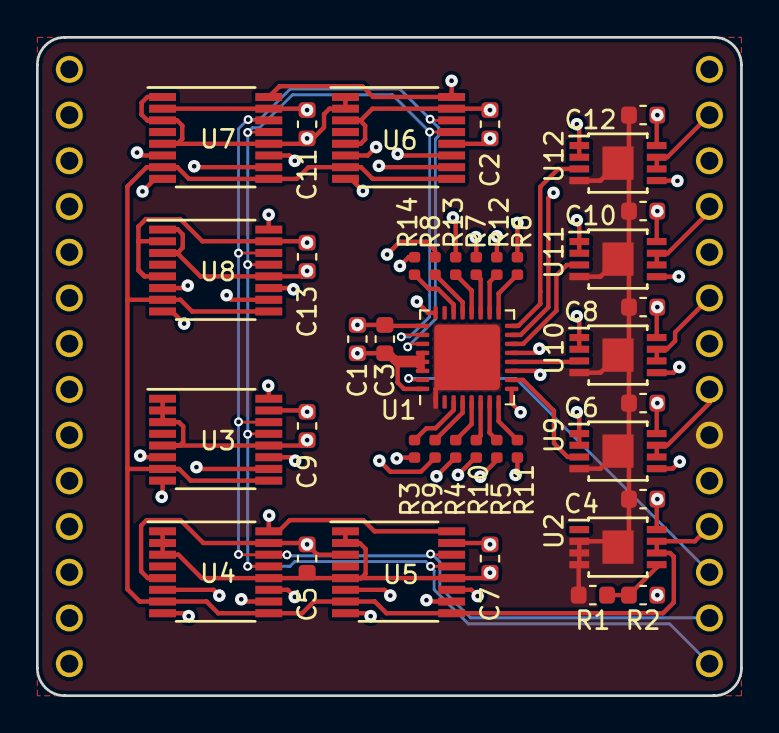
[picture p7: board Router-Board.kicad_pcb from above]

Board: 4 copper layers, 39.1 x 36.6 mm, 41 parts (1 on the bottom side), 61 nets.

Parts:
C1, C2, C3, C4, C5, C6, C7, C8, C9, C10, C11, C12, C13: 1uF; C_0603_1608Metric
J2, J3: Conn_01x14_Male; PinHeader_1x14_P2.54mm_Vertical
R1, R2: 51k; R_0603_1608Metric
R3, R4, R5, R6, R7, R8, R9, R10, R11, R12, R13, R14: 330; R_0402_1005Metric
U1: ADG2128; QFN-32-1EP_5x5mm_P0.5mm_EP3.65x3.65mm
U2, U9, U10, U11, U12: LME49726MY/NOPB; TSSOP-8_3x3mm_P0.65mm-EP
U3, U4, U5, U6, U7, U8: DS1881E-050+; TSSOP-16_4.4x5mm_P0.65mm

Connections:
/ANAGND: C4.2, C6.2, C8.2, C10.2, C12.2, J3.6, R1.1, U1.1, U1.33, U2.0, U2.2, U2.3, U2.4, U9.0, U9.4, U10.0, U10.4, U11.0, U11.4, U12.0, U12.4
/ANAVcc: C4.1, C6.1, C8.1, C10.1, C12.1, J3.5, R2.2, U1.24, U2.8, U3.16, U4.16, U5.16, U6.16, U7.16, U8.16, U9.8, U10.8, U11.8, U12.8
/Biased-In-L-0: J2.3, U3.8
/Biased-In-L-1: J2.5, U4.8
/Biased-In-L-2: J2.7, U5.8
/Biased-In-L-3: J2.9, U6.8
/Biased-In-L-4: J2.11, U7.8
/Biased-In-L-5: J2.13, U8.8
/Biased-In-R-0: J2.4, U3.10
/Biased-In-R-1: J2.6, U4.10
/Biased-In-R-2: J2.8, U5.10
/Biased-In-R-3: J2.10, U6.10
/Biased-In-R-4: J2.12, U7.10
/Biased-In-R-5: J2.14, U8.10
/GND: C1.2, C2.2, C3.2, C5.2, C7.2, C9.2, C11.2, C13.2, J2.2, U1.28, U1.29, U1.30, U1.32, U3.1, U3.2, U3.3, U3.5, U3.12, U4.1, U4.2, U4.3, U4.12, U5.1, U5.2, U5.5, U5.12, U6.1, U6.2, U6.12, U7.1, U7.3, U7.5, U7.12, U8.1, U8.3, U8.12
/Out-L-0: J3.7, U9.6, U9.7
/Out-L-1: J3.9, U10.6, U10.7
/Out-L-2: J3.11, U11.6, U11.7
/Out-L-3: J3.13, U12.6, U12.7
/Out-R-0: J3.8, U9.1, U9.2
/Out-R-1: J3.10, U10.1, U10.2
/Out-R-2: J3.12, U11.1, U11.2
/Out-R-3: J3.14, U12.1, U12.2
/SCL: J3.2, U1.27, U3.14, U4.14, U5.14, U6.14, U7.14, U8.14
/SDA: J3.1, U1.26, U3.13, U4.13, U5.13, U6.13, U7.13, U8.13
/Switch-In-L-0: R3.1, U3.6
/Switch-In-L-1: R4.1, U4.6
/Switch-In-L-2: R5.1, U5.6
/Switch-In-L-3: R6.1, U6.6
/Switch-In-L-4: R7.1, U7.6
/Switch-In-L-5: R8.1, U8.6
/Switch-In-R-0: R9.1, U3.11
/Switch-In-R-1: R10.1, U4.11
/Switch-In-R-2: R11.1, U5.11
/Switch-In-R-3: R12.1, U6.11
/Switch-In-R-4: R13.1, U7.11
/Switch-In-R-5: R14.1, U8.11
/Switch-Out-L-0: U1.9, U9.5
/Switch-Out-L-1: U1.11, U10.5
/Switch-Out-L-2: U1.13, U11.5
/Switch-Out-L-3: U1.15, U12.5
/Switch-Out-R-0: U1.10, U9.3
/Switch-Out-R-1: U1.12, U10.3
/Switch-Out-R-2: U1.14, U11.3
/Switch-Out-R-3: U1.16, U12.3
/Vcc: C1.1, C2.1, C3.1, C5.1, C7.1, C9.1, C11.1, C13.1, J2.1, U1.25, U3.15, U4.5, U4.15, U5.3, U5.15, U6.3, U6.5, U6.15, U7.2, U7.15, U8.2, U8.5, U8.15
/VccDiv2: J3.4, U2.6, U2.7, U3.7, U3.9, U4.7, U4.9, U5.7, U5.9, U6.7, U6.9, U7.7, U7.9, U8.7, U8.9
/~RESET: J3.3, U1.31
unnamed: R1.2, R2.1, U2.5
unnamed: R3.2, U1.3
unnamed: R4.2, U1.5
unnamed: R5.2, U1.7
unnamed: R6.2, U1.17
unnamed: R7.2, U1.19
unnamed: R8.2, U1.21
unnamed: R9.2, U1.4
unnamed: R10.2, U1.6
unnamed: R11.2, U1.8
unnamed: R12.2, U1.18
unnamed: R13.2, U1.20
unnamed: R14.2, U1.22

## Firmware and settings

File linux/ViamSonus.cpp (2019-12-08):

/*
File:   ViamSonus.cpp
Author: J. Ian Lindsay
Date:   2014.05.19

Copyright (C) 2014 J. Ian Lindsay
All rights reserved.

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

This is an example program that shows the basic operation of ViamSonus. It is
  intended that this be run on a linux SBC.

*/


#include <ViamSonus.h>
#include <Wire.h>

#define VERSION_STRING "v1.1"

TwoWire* i2c  = nullptr;
ViamSonus* vs = nullptr;


#include <stdint.h>
#include <inttypes.h>
#include <ctype.h>
#include <stdio.h>
#include <stdlib.h>
#include <stdarg.h>
#include <string.h>
#include <unistd.h>
#include <fstream>
#include <iostream>

#include <fcntl.h>
#include <sys/signal.h>
#include <errno.h>
#include <termios.h>
#include <time.h>


/**
* The help function. We use printf() because we are certain there is a user at the other end of STDOUT.
*/
void printUsage() {
	printf("================================================================================\n");
	printf("Bus and channel selection:\n");
	printf("================================================================================\n");
	printf("    --i2c-dev   Specify the i2c device to use.\n");
	printf("-i  --input     input pin (0-11)\n");
	printf("-o  --output    output pin (0-7)\n");
	printf("\n");

	printf("================================================================================\n");
	printf("Options that operate on channels:\n");
	printf("================================================================================\n");
	printf("-r  --route     Route the given input to the given output.\n");
	printf("-u  --unroute   Unroute the given input from the given output(s). If no output\n");
	printf("                 is specified, we will unroute the given input from all outputs.\n");
	printf("-v  --volume    Specify the value of the linear potentiometer (0-255).\n");
	printf("                 If no output is specified, we will adjust all outputs.\n");
	printf("-m  --mute      Mutes a specified output channel. If no output channel is\n");
	printf("                 specified, we will mute all outputs. Note that muting an output\n");
	printf("                 has no effect on the route.\n");
	printf("\n");

	printf("================================================================================\n");
	printf("Meta:\n");
	printf("================================================================================\n");
	printf("-v  --version   Print the version and exit.\n");
	printf("-h  --help      Print this output and exit.\n");
	printf("-s  --status    Read and print the present condition of the PCB.\n");
	printf("-S  --serialize Pack the hardware state into a buffer.\n");
	printf("    --reset     Reset the PCB back to it's power-on state.\n");
	printf("    --enable    Enable a PCB that was previously disabled.\n");
	printf("    --disable   Disable the PCB. Opens all switches and mutes all outputs.\n");
	printf("\n\n");
}



/*******************************************************************************
* Entry-point for a linux build...
********************************************************************************/

int main(int argc, char *argv[]) {
	char operation       = '.';     // No operation.
	uint8_t volume       = 128;
	uint8_t input_chan   = 255;
	uint8_t output_chan  = 255;

	// Parse through all the command line arguments and flags...
	// Please note that the order matters. Put all the most-general matches at the bottom of the loop.
	for (int i = 1; i < argc; i++) {
		if ((strcasestr(argv[i], "--help")) || ((argv[i][0] == '-') && (argv[i][1] == 'h'))) {
			printUsage();
			exit(0);
		}
		else if ((strcasestr(argv[i], "--version")) || ((argv[i][0] == '-') && (argv[i][1] == 'v'))) {
			printf("%s v%s\n\n", argv[0], VERSION_STRING);
			exit(0);
		}
		else if (argc - i >= 2) {    // Compound arguments go in this case block...
			if (strcasestr(argv[i], "--i2c-dev")) {
				i2c = new TwoWire(argv[++i]);          // Fire up the i2c interface...
				i2c->setDebug(true);
			}
			else if (strcasestr(argv[i], "--volume") || ((argv[i][0] == '-') && (argv[i][1] == 'v'))) {
				int temp_vol = atoi(argv[++i]);
				if ((temp_vol > 255) || (temp_vol < 0)) {
					printf("Volume needs to be specified as an integer between 0 and 255.\n");
					exit(0);
				}
				volume = (uint8_t) temp_vol;
				operation = 'v';
			}
			else if (strcasestr(argv[i], "--input") || ((argv[i][0] == '-') && (argv[i][1] == 'i'))) {
				int temp = atoi(argv[++i]);
				if ((temp > 11) || (temp < 0)) {
					printf("Input channel must be between 0 and 11.\n");
					exit(0);
				}
				input_chan = (uint8_t) temp;
			}
			else if (strcasestr(argv[i], "--output") || ((argv[i][0] == '-') && (argv[i][1] == 'o'))) {
				int temp = atoi(argv[++i]);
				if ((temp > 7) || (temp < 0)) {
					printf("Output channel must be between 0 and 7.\n");
					exit(0);
				}
				output_chan = (uint8_t) temp;
			}
			else {
				i++;
			}
		}
		else if (strcasestr(argv[i], "--enable")) {
			operation = 'e';
		}
		else if (strcasestr(argv[i], "--disable")) {
			operation = 'd';
		}
		else if (strcasestr(argv[i], "--reset")) {
			operation = 'x';
		}
		else if (strcasestr(argv[i], "--route") || ((argv[i][0] == '-') && (argv[i][1] == 'r'))) {
			operation = 'r';
		}
		else if (strcasestr(argv[i], "--status") || ((argv[i][0] == '-') && (argv[i][1] == 's'))) {
			operation = 's';
		}
		else if (strcasestr(argv[i], "--serialize") || ((argv[i][0] == '-') && (argv[i][1] == 'S'))) {
			operation = 'S';
		}

		else if (strcasestr(argv[i], "--unroute") || ((argv[i][0] == '-') && (argv[i][1] == 'u'))) {
			operation = 'u';
		}

		else {
			printf("Unhandled argument: %s\n", argv[i]);
			printUsage();
			exit(1);
		}
	}


	if ((nullptr != i2c) && (i2c->busOnline())) {
		vs = new ViamSonus(255);
		// Since this program will do its job and exit immediately (taking the
		//   state of the switch with it), we need to instruct the class to not
		//   disable the hardware when the program exits.
		vs->preserveOnDestroy(true);
		vs->init(i2c);

		ViamSonusError result = ViamSonusError::NO_ERROR;
		switch (operation) {
			case 'r':
				result = vs->route(output_chan, input_chan);
				break;
			case 'u':
				if (input_chan == 255) {
					result = vs->unroute(output_chan);
				}
				else {
					result = vs->unroute(output_chan, input_chan);
				}
				break;
			case 'v':
				if (output_chan == 255) {
					for (int i = 0; i < 8; i++) {
						result = vs->setVolume(i, volume);
					}
				}
				else {
					result = vs->setVolume(output_chan, volume);
				}
				break;
			case '.':
				// No operation selected.
				printf("Nothing to do.\n");
				exit(0);
				break;
			default:
				printf("Unhandled case.\n");
				break;
		}

		switch (result) {
			case ViamSonusError::NO_ERROR:
				printf("Operation completed with success.\n");
				break;
			case ViamSonusError::INPUT_DISPLACED:
				printf("Operation completed with success, but we displaced a previously established route.\n");
				break;
			case ViamSonusError::BAD_COLUMN:
				printf("Error: Output channel is out of range.\n");
				break;
			case ViamSonusError::BAD_ROW:
				printf("Error: Input channel is out of range.\n");
				break;
			case ViamSonusError::UNROUTE_FAILED:
				printf("Error: Failed to unroute the given channels.\n");
				break;
			default:
				printf("Unhandled case: (%s).\n", ViamSonus::errorToStr(result));
				break;
		}
	}
	else {
		printf("You need to supply a valid i2c device.\n");
	}

	exit(0);
}

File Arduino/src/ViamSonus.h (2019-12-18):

/*
File:   ViamSonus.h
Author: J. Ian Lindsay
Date:   2019.11.16

Copyright 2019 Manuvr, Inc

Licensed under the Apache License, Version 2.0 (the "License");
you may not use this file except in compliance with the License.
You may obtain a copy of the License at

    http://www.apache.org/licenses/LICENSE-2.0

Unless required by applicable law or agreed to in writing, software
distributed under the License is distributed on an "AS IS" BASIS,
WITHOUT WARRANTIES OR CONDITIONS OF ANY KIND, either express or implied.
See the License for the specific language governing permissions and
limitations under the License.


Digipots start at i2c address 0x28, and there are 6 of them.
Crosspoint switch is at address 0x70.
*/

#ifndef __VIAMSONUS_DRIVER_H__
#define __VIAMSONUS_DRIVER_H__

#include <DS1881.h>
#include <ADG2128.h>
#include <StringBuilder.h>
#include <PriorityQueue.h>

class ViamSonus;
class VSOGroup;
class VSIGroup;

#define VIAMSONUS_SERIALIZE_VERSION  1
#define VIAMSONUS_SERIALIZE_SIZE     (5 + ADG2128_SERIALIZE_SIZE + (DS1881_SERIALIZE_SIZE*6))


/* Values that set limits on channel storage requirements. */
#define VSIG_FIXED_SER_SIZE    6
#define VSOG_FIXED_SER_SIZE    4
#define VSCG_FIXED_SER_SIZE    4
#define VSCG_MAX_NAME_LENGTH  32

/* ViamSonus class flags */
#define VIAMSONUS_FLAG_PRESERVE_STATE 0x00000001  // Preserve hardware states.

#define VIAMSONUS_FLAG_FOUND_SWITCH   0x02000000  // Found the switch.
#define VIAMSONUS_FLAG_FOUND_POT_0    0x04000000  // Found this potentiometer.
#define VIAMSONUS_FLAG_FOUND_POT_1    0x08000000  // Found this potentiometer.
#define VIAMSONUS_FLAG_FOUND_POT_2    0x10000000  // Found this potentiometer.
#define VIAMSONUS_FLAG_FOUND_POT_3    0x20000000  // Found this potentiometer.
#define VIAMSONUS_FLAG_FOUND_POT_4    0x40000000  // Found this potentiometer.
#define VIAMSONUS_FLAG_FOUND_POT_5    0x80000000  // Found this potentiometer.

#define VIAMSONUS_FLAG_RESET_MASK     0xFE000000  // Bits to preserve through reset.
#define VIAMSONUS_FLAG_ALL_DEVS_MASK  0xFE000000  // All devices found.
#define VIAMSONUS_FLAG_SERIAL_MASK    0x000000FF  // Only these bits are serialized.


/* InputChannel flags */
#define VSCG_FLAG_ALLOW_MIX           0x0001  // This channel is safe to mix.
#define VSCG_FLAG_MONITOR             0x0002  // Monitor this channel via ADC.
#define VSCG_FLAG_AUTO_APPLY          0x0004  // This group should apply to hardware on every change.


enum class ViamSonusError : int8_t {
  INPUT_DISPLACED  = 4,   // There was no error, but a channel-routing operation has displaced a previously-routed input.
  DEVICE_DISABLED  = 3,   // A caller tried to set a wiper while the device is disabled. This may work...
  PEGGED_MAX       = 2,   // There was no error, but a call to change a wiper setting pegged the wiper at its highest position.
  PEGGED_MIN       = 1,   // There was no error, but a call to change a wiper setting pegged the wiper at its lowest position.
  NO_ERROR         = 0,   // There was no error.
  ABSENT           = -1,  // A part on the board appears to not be connected to the bus.
  BUS              = -2,  // Something went wrong with the i2c bus.
  ALREADY_AT_MAX   = -3,  // A caller tried to increase the value of the wiper beyond its maximum.
  ALREADY_AT_MIN   = -4,  // A caller tried to decrease the value of the wiper below its minimum.
  INVALID_POT      = -5,  // There aren't that many potentiometers.
  UNROUTE_FAILED   = -6,  // We tried to unroute a signal from an output and failed.
  BAD_COLUMN       = -7,  // Column was out-of-bounds.
  BAD_ROW          = -8,  // Row was out-of-bounds.
  SWITCH_COLLISION = -9,  // Command would violate a row or col cardinality constraint.
  GEN_SWITCH_FAULT = -10  // A general switch failure.
};

/*
* These are operations that happen on timers to facilitate certain use-cases,
*   ease peak resource usage, or implement UI features.
*/
enum class VSOpcode : uint8_t {
  UNDEFINED        = 0,   // Default uninitialized value.
  CHAN_VOLUME_SET  = 1,   // Set the channel volume to the value at the operand.
  CHAN_VOLUME_INC  = 2,   // Bump the channel volume by the amount at the operand.
  CHAN_VOLUME_DEC  = 3,   // Cut the channel volume by the amount at the operand.
  CHAN_ROUTE       = 4,   // Routes the input channel to the output channel.
  CHAN_UNROUTE     = 5,   // Unroutes the input channel from the output channel.
  GRP_VOLUME_SET   = 6,   // Set the group volume to the value at the operand.
  GRP_VOLUME_INC   = 7,   // Bump the group volume by the amount at the operand.
  GRP_VOLUME_DEC   = 8,   // Cut the group volume by the amount at the operand.
  GRP_ROUTE        = 9,   // Routes the input group to the output group.
  GRP_UNROUTE      = 10,  // Unroutes the input group from the output group.
  ADC_READ         = 11   // Reads an ADC associated with a channel.
};


// This struct defines an input pin on the PCB.
typedef struct cps_input_channel_t {
  char*    name;       // A name for this input. Not required.
  uint8_t  i_chan;     // The row in the crosspoint switch associated with this input.
  uint8_t  o_chans;    // A flag field indicating which columns are presently bound to this row.
  uint16_t flags;      // Flags on this channel.
} CPInputChannel;


// This struct defines an output pin on the PCB.
typedef struct cps_output_channel_t {
  char*    name;       // A name for this output. Not required.
  uint16_t i_chans;    // A flag field indicating which rows are presently bound to this column.
  uint8_t  o_chan;     // The column in the crosspoint switch associated with this output.
  uint8_t  flags;      // Flags on this channel.
} CPOutputChannel;


/* This class is used to schedule class operations. */
class VSPendingOperation {
  public:
    uint32_t    at_ms          = 0;
    uint8_t     recycle_count  = 0;
    uint8_t     recycle_period = 0;
    VSOpcode op = VSOpcode::UNDEFINED;
};
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

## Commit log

2019-11-19 Rudaments of Arduino driver. Schematic. README. Renders.
2019-11-19 More driver bulk import with a few passes of rework.
    [ViamSonus.cpp, ViamSonus.h, ViamSonusBasic.ino]
2019-11-23 Adding hardware files. Updated schematic with in-practice resistor values.
    [BOM-Router-Board.csv, Router-Board.kicad_pcb, Router-Board.sch]
2019-11-24 Correcting filename mistake. Adding schematic for recommended input circuit.
    [Basic-Connector-Board.sch]
2019-11-24 Arduino driver compiles again. Untested.
2019-11-24 Example improvements. Fixing library rename mistake.
    [Router-Board.sch]
2019-11-25 Routing code cleaned up. Switch is now behaving predictably.
2019-11-26 Fixing things after upheaval in dependencies.
    [ViamSonus.cpp, ViamSonusBasic.ino]
2019-11-26 Changing output cap values for better low-end response.
    [Basic-Connector-Board.sch]
2019-11-27 Adding linux tool. No i2c abstraction yet.
2019-11-29 Adding regulator to connector board. Input-side circuit is now correct.
    [Basic-Connector-Board.kicad_pcb, Basic-Connector-Board.sch]
2019-11-30 More connector board work.
    [Basic-Connector-Board.sch]
2019-11-30 Adding 3.3v analog regulator symbol.
2019-12-05 Connector board work.
    [Basic-Connector-Board.kicad_pcb, Basic-Connector-Board.sch]
2019-12-07 More hardware work. More work on channel groups.
    [Basic-Connector-Board.csv, Basic-Connector-Board.kicad_pcb, Basic-Connector-Board.sch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]
2019-12-08 More work on the advanced usage example. Compiles and crashes. Basic works great.
    [ViamSonus.cpp, ViamSonus.h, ViamSonusAdvanced.ino]
2019-12-18 Fixes, debug cleanup, more unserialize support.
    [ViamSonus.cpp, ViamSonus.h, ViamSonusAdvanced.ino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]
2019-12-18 Fixing a bug in channel swap.
    [ViamSonusAdvanced.ino]
2020-02-22 Reflecting dependency addition to Library manager. Generalizing away from Teensy3.x.
